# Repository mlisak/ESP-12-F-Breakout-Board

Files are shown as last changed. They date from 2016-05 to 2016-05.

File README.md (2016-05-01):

## ESP-12-F Breakout Board
This is a simple plug&play breakout board for ESP-12-F cheap Wi-Fi board (22 pins with SPI, 4 MB flash). The design is small, two-sided, and fits nicely on a breadboard. All 22 pins are available on pin headers. The board includes micro USB port, 3.3 V stabilizer, flash/reset buttons and USB-to-serial converter (CH340G/CH340T). Works well with NodeMCU firmware.

Schematic is based on [this design](https://github.com/markbeee/ESP8266_Breakout_Board).

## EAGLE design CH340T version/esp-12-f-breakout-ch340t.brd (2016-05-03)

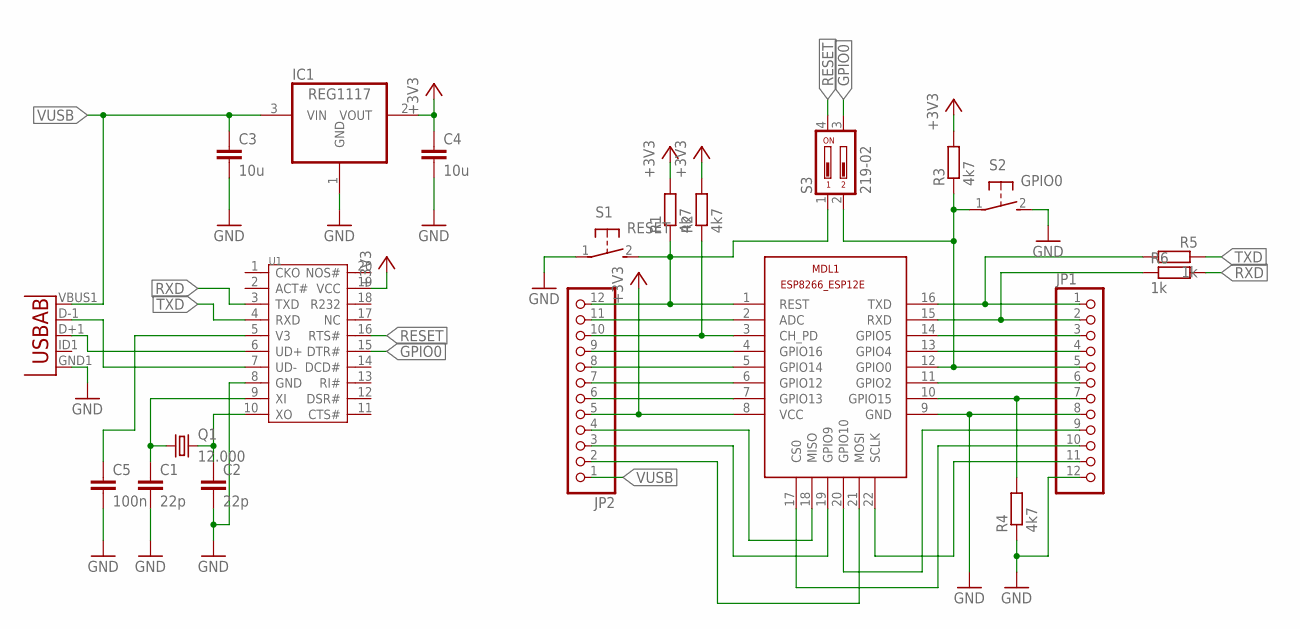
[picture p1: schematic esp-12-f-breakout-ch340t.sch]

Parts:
C1, C2: 22p; C0805
C3, C4: 10u; C0805
C5: 100n; C0805
IC1: REG1117; SOT223
JP1, JP2: PINHD-1X12; 1X12
MDL1: ESP8266-12EESP8266-ESP12E; ESP8266-ESP12E
Q1: 12.000; HC49UP
R1, R2, R3, R4: 4k7; M0805
R5, R6: 1k; M0805
S1: RESET; DTSM-3
S2: GPIO0; DTSM-3
S3: 219-02; CTS-219-02
U1: CH340T; SSOP20
U2: USB""; USB-MICRO-SMD

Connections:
+3V3: C4.1, IC1.2 (VOUT), JP2.5, MDL1.8 (VCC), R1.2, R2.2, R3.2, U1.19 (VCC)
GND: C1.2, C2.2, C3.2, C4.2, C5.2, IC1.1 (GND), JP1.8, JP1.12, MDL1.9 (GND), R4.1, S1.1, S2.2, U1.8 (GND), U2.GND1 (GND)
GPIO0: S3.3, U1.15 (DTR#)
unnamed: JP2.12, MDL1.1 (REST), R1.1, S1.2, S3.1
unnamed: JP2.11, MDL1.2 (ADC)
unnamed: JP2.10, MDL1.3 (CH_PD), R2.1
unnamed: JP2.9, MDL1.4 (GPIO16)
unnamed: JP2.8, MDL1.5 (GPIO14)
unnamed: JP2.7, MDL1.6 (GPIO12)
unnamed: JP2.6, MDL1.7 (GPIO13)
unnamed: JP2.4, MDL1.18 (MISO)
unnamed: JP2.3, MDL1.19 (GPIO9)
unnamed: JP1.9, MDL1.20 (GPIO10)
unnamed: JP1.10, MDL1.17 (CS0)
unnamed: JP1.11, MDL1.22 (SCLK)
unnamed: JP2.2, MDL1.21 (MOSI)
unnamed: JP1.7, MDL1.10 (GPIO15), R4.2
unnamed: JP1.6, MDL1.11 (GPIO2)
unnamed: JP1.5, MDL1.12 (GPIO0), R3.1, S2.1, S3.2
unnamed: JP1.4, MDL1.13 (GPIO4)
unnamed: JP1.3, MDL1.14 (GPIO5)
unnamed: JP1.2, MDL1.15 (RXD), R6.1
unnamed: JP1.1, MDL1.16 (TXD), R5.2
unnamed: C1.1, Q1.1, U1.9 (XI)
unnamed: C2.1, Q1.2, U1.10 (XO)
unnamed: U1.7 (UD-), U2.D-1 (D-)
unnamed: U1.6 (UD+), U2.D+1 (D+)
RESET: S3.4, U1.16 (RTS#)
RXD: R6.2, U1.3 (TXD)
TXD: R5.1, U1.4 (RXD)
V3: C5.1, U1.5 (V3)
VUSB: C3.1, IC1.3 (VIN), JP2.1, U2.VBUS1 (VBUS)

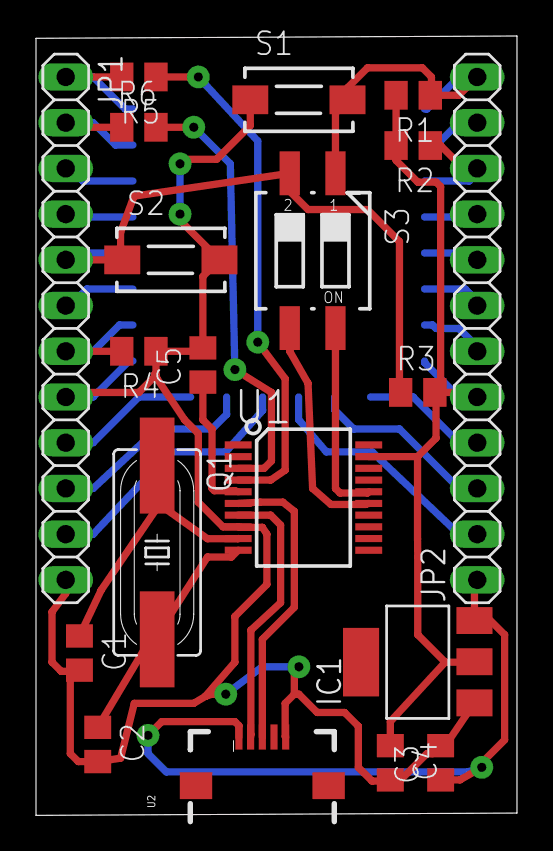
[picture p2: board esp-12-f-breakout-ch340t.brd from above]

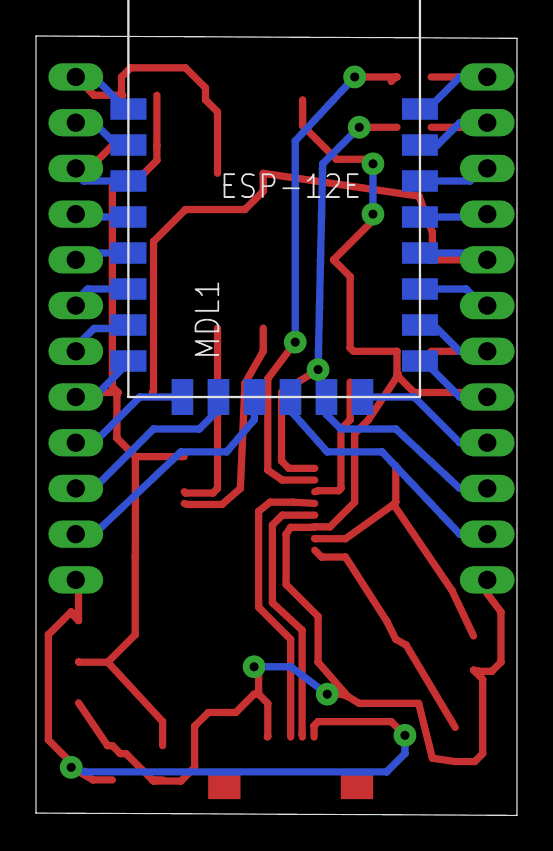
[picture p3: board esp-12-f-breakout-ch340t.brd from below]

Board: 2 copper layers, 26.7 x 43.3 mm, 22 parts (2 on the bottom side), 32 nets.

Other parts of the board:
U$1: MITSUDOMOE
